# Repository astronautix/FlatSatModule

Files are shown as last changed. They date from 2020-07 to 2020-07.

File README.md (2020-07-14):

# Introduction

This KiCAD project is part of the Astronautix FlatSat project, which aims to create an extensible platform for nanosatellite subsystem prototyping and experimentation.

The FlatSat platform is composed of a main metallic support plate, which can possibly host 8 submodules in star configuration. Each submodule is composed of a STM32F429IDISCOVERY board and a custom adapter hat (**this project**).

All modules are hooked to a central hub via a sub-d DB26HD harness. The central hub has the main purpose of routing UART signals, regulating power (dispatched via sub-d, switchable) and linking all submodules together.

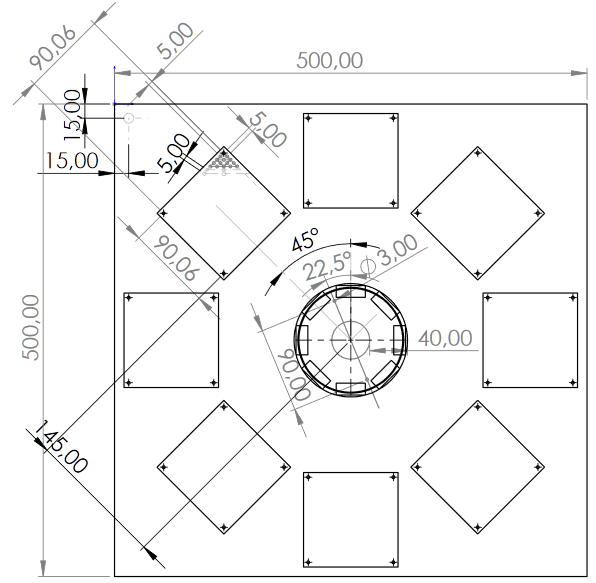
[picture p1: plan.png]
Board plan


# The STM32F429IDISCOVERY adapter

## V1

The adapter hats has the primary purpose of routing all the needed bus signal from the STM32 board to the sub-d connector. As an added bonus, a microSD connector has been inserted to provide autonomous data storage, and a breakout header is provided for signal debugging purposes. Two LEDs are present, one to signal for the powering of the board, and the other for the SD card detection. Finally, a jumper is provided for 5V sub-d cutoff if needed (we might want to bring power through USB directly)

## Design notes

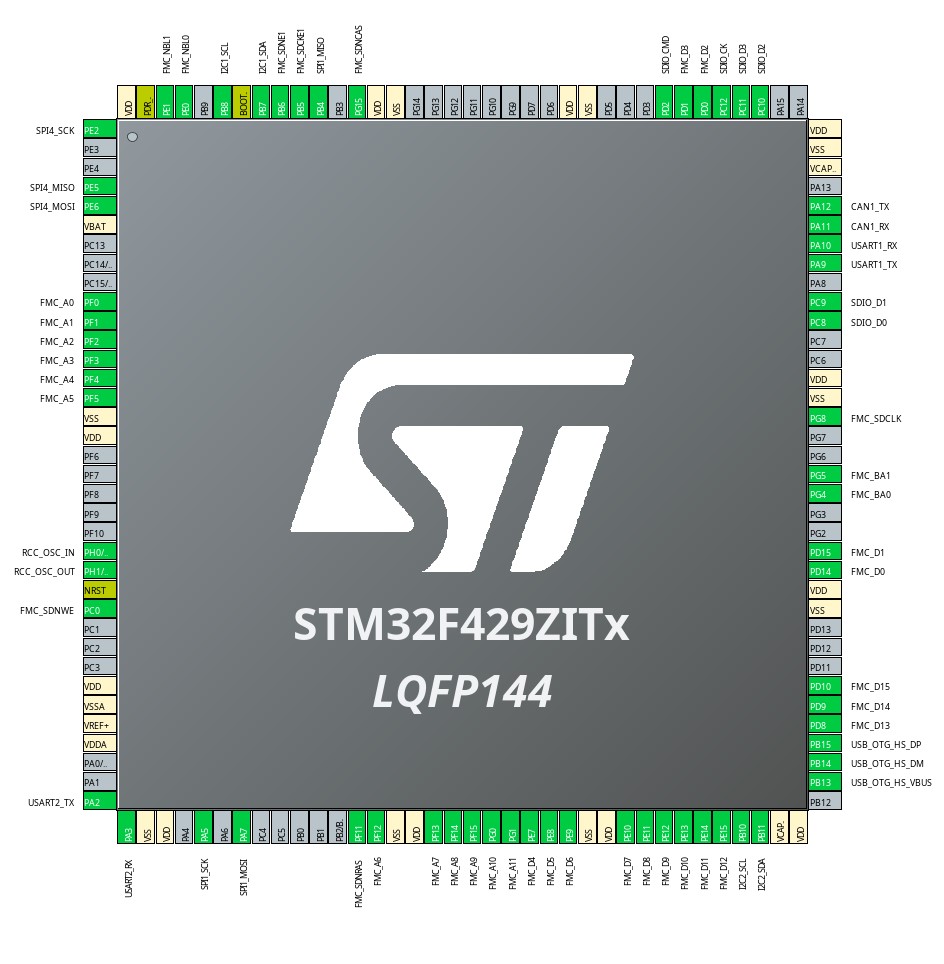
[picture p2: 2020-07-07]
reference_pinout.jpg

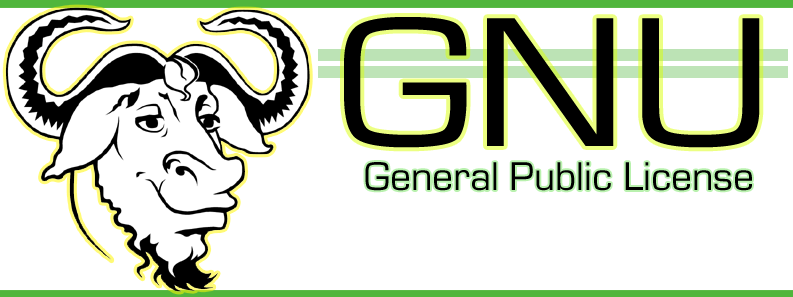
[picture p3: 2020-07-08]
GNU-General-Public-License.png

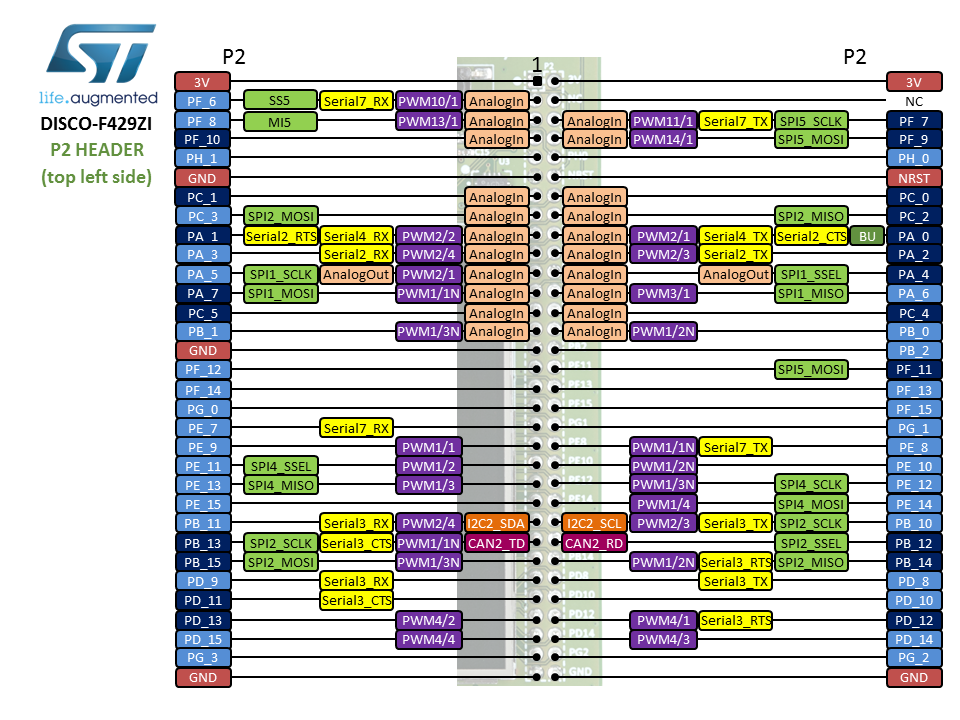
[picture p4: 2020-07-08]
disco_f429zi_2017-07-25_slide2.png

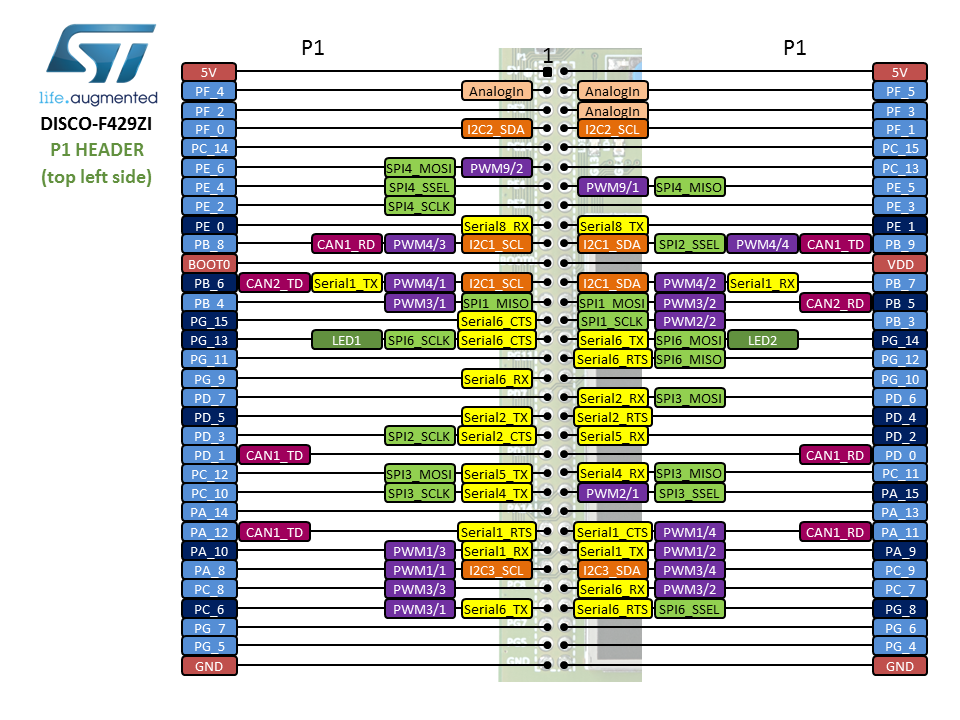
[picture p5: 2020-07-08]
disco_f429zi_2017-07-25_slide1.png

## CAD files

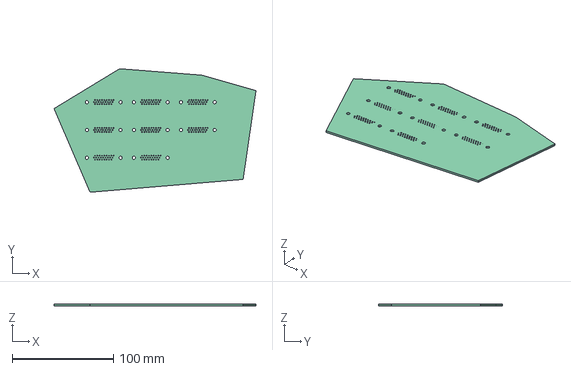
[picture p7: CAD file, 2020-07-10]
kicadstepup.FCStd
199.4 x 121.9 x 1.60 mm

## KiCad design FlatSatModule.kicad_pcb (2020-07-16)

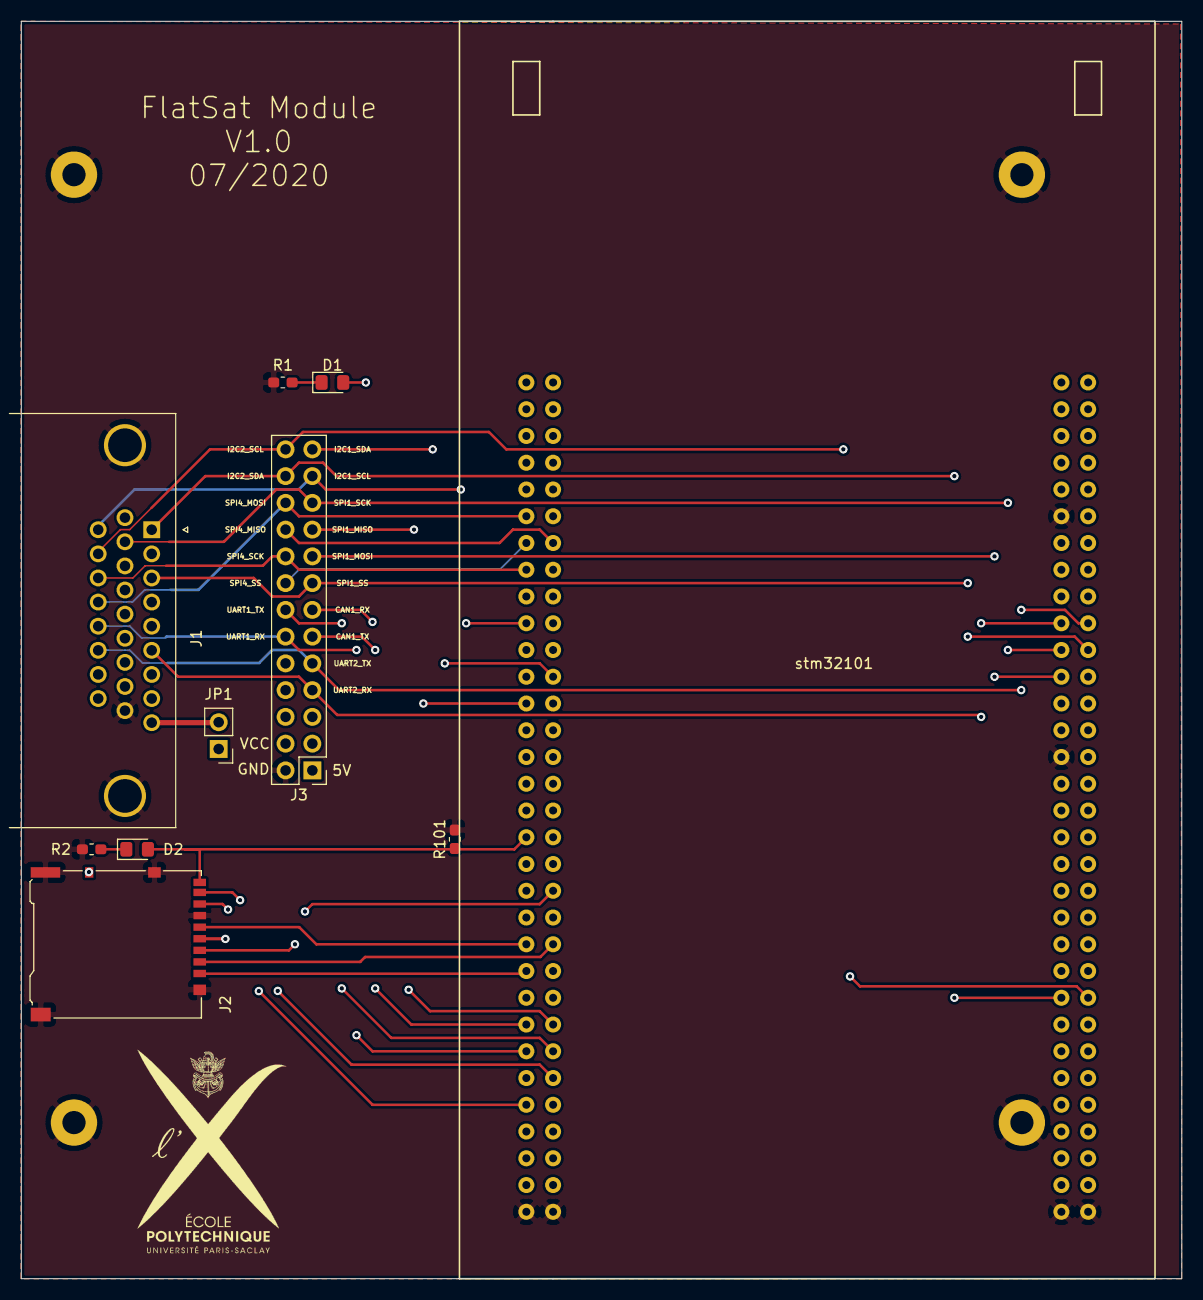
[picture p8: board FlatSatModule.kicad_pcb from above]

Board: 4 copper layers, 110.2 x 119.4 mm, 15 parts (0 on the bottom side), 31 nets.

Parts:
D1, D2: LED; LED_0805_2012Metric_Pad1.15x1.40mm_HandSolder
G1: LOGO; X-LOGO
H1, H2, H3, H4: MountingHole_Pad; MountingHole_2.2mm_M2_Pad
J1: DB26_Male_HighDensity_MountingHoles; DSUB-26-HD_Male_Horizontal_P2.29x1.98mm_EdgePinOffset8.35mm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
J2: Micro_SD_Card_Det; microSD_HC_Hirose_DM3AT-SF-PEJM5
J3: HEADER_13x2; PinHeader_2x13_P2.54mm_Vertical
JP1: Jumper_2_Bridged; PinHeader_1x02_P2.54mm_Vertical
R1, R2, R101: R; R_0603_1608Metric_Pad1.05x0.95mm_HandSolder
stm32101: STM32F429i-Discovery; stm32f429i-disco

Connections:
/5V: J3.1, JP1.1, stm32101.1, stm32101.2
/CAN1_RX: J1.14, J3.13, stm32101.50
/CAN1_TX: J1.5, J3.11, stm32101.49
/I2C1_SCL: J1.19, J3.23, stm32101.19
/I2C1_SDA: J1.10, J3.25, stm32101.24
/I2C2_SCL: J1.20, J3.26, stm32101.112
/I2C2_SDA: J1.1, J3.24, stm32101.111
/SD_CLK: J2.5, stm32101.43
/SD_CMD: J2.3, stm32101.40
/SD_D0: J2.7, stm32101.55
/SD_D1: J2.8, stm32101.54
/SD_D2: J2.1, stm32101.45
/SD_D3: J2.2, stm32101.44
/SD_DET: D2.2, J2.9, R101.1, stm32101.35
/SPI1_MISO: J1.2, J3.19, stm32101.25
/SPI1_MOSI: J1.12, J3.17, stm32101.87
/SPI1_SCK: J1.11, J3.21, stm32101.85
/SPI1_SS: J1.3, J3.15, stm32101.86
/SPI4_MISO: J1.13, J3.20, stm32101.14
/SPI4_MOSI: J1.22, J3.22, stm32101.11
/SPI4_SCK: J1.21, J3.18, stm32101.15
/SPI4_SS: J1.4, J3.16, stm32101.13
/UART1_RX: J1.23, J3.12, stm32101.51
/UART1_TX: J1.15, J3.14, stm32101.52
/UART2_RX: J1.6, J3.7, stm32101.83
/UART2_TX: J1.24, J3.9, stm32101.84
GND: H1.1, H2.1, H3.1, H4.1, J1.0, J1.18, J2.6, J2.11, J3.2, R1.2, R2.2, R101.2, stm32101.63, stm32101.64, stm32101.75, stm32101.93, stm32101.127, stm32101.128
unnamed: D1.1, R1.1
unnamed: D2.1, R2.1
unnamed: J1.9, JP1.2
VCC: D1.2, J1.8, J2.4, J2.10, J3.4, stm32101.65, stm32101.66

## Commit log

2020-06-24 first init
    [FlatSatModule.kicad_pcb, FlatSatModule.sch]
2020-06-30 first routing, lost schematic
    [FlatSatModule.kicad_pcb, FlatSatModule.sch]
2020-06-30 recovered schematic
    [FlatSatModule.sch]
2020-07-07 updated wiring + wired SD card
    [FlatSatModule.kicad_pcb, FlatSatModule.sch]
2020-07-07 add USARTs and gnd plane filling
    [FlatSatModule.kicad_pcb, FlatSatModule.sch]
2020-07-07 Add SS for SPI buses
    [FlatSatModule.kicad_pcb, FlatSatModule.sch]
2020-07-08 clarify schematic
    [FlatSatModule.sch]
2020-07-10 Redo routing
    [FlatSatModule.kicad_pcb, FlatSatModule.sch]
2020-07-10 add freecad file
    [kicadstepup.FCStd]
2020-07-13 Fix track size
    [FlatSatModule.kicad_pcb]
2020-07-13 Added silkscreen text
    [FlatSatModule.kicad_pcb]
2020-07-14 improve schematic and replace footprints
    [FlatSatModule.kicad_pcb, FlatSatModule.sch]
2020-07-14 Add mounting holes, replace microSD footprint and move components
    [FlatSatModule.kicad_pcb]
2020-07-14 Add plate plan to readme
2020-07-14 Replaced DB 26 HD footprint, cleaned layout and few fixes...
    [FlatSatModule.kicad_pcb, FlatSatModule.sch]
2020-07-15 Add X logo, reset version to 1.0 and move microSD label
    [FlatSatModule.kicad_pcb, FlatSatModule.sch]
2020-07-15 wire sd_det to stm32 and correct stm32 footprint
    [FlatSatModule.kicad_pcb, FlatSatModule.sch]
2020-07-16 Added pull down resistor for SD card detect and few track clean.
    [FlatSatModule.kicad_pcb, FlatSatModule.sch]
